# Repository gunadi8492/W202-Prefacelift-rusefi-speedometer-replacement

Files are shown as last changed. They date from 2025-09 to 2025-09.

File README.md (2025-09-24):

# Mercedes-Benz W202 Speedometer Replacement (rusEFI)

This project is a custom **speedometer replacement** for a **1994 Mercedes-Benz W202 C180 (pre-facelift)** running on a **rusEFI open-source standalone ECU**.  

⚠️ **Disclaimer:**  
This is an **open-source project** provided *as-is*, without any warranty or support.  
It is intended strictly for **educational and hobbyist purposes only**.  

---

## 📖 Background

This project builds upon the excellent work by [Pazi88](https://github.com/pazi88/E12_CAN_gauges), originally designed for a BMW E12 speedometer.  

Test implementation has been successfully tested with **rusEFI Dash CANBUS** with a BMW E46 CAN Dash setting, supporting:  
- **RPM**  
- **VSS (Vehicle Speed Sensor)**  
- **CLT (Coolant Temperature)**  

---

## 📟 Hardware Integration

For this adaptation, additional components were introduced:  
- **Nextion Enhanced 3.5” display**  
- **STM32F103C8T6 “Blue Pill” MCU**  

These allow enhanced visualization of live ECU data.  

The **schematic and hardware design** were adapted specifically to meet the requirements of this W202 project.  

---

## 💻 Firmware Status

- Development for the **STM32F103C8T6** firmware is still in progress.  
- For working code examples and inspiration, refer to Pazi’s original repository.  

---

## ⚠️ Important Notice

- ✅ **Responsibility**: You are solely responsible for checking and complying with all **local laws and regulations** before using this project.  
- ✅ **Road Use**: Compliance with vehicle safety and legal standards for public road use is mandatory.  
- ✅ **Liability**: No liability is accepted for misuse, damages, or legal issues resulting from use of this project.  
- 🚫 **Commercial Use**: Strictly prohibited.  
- 📌 **Recommendation**: Ensure you fully understand the project before attempting implementation.  

---

## 📜 License

This project is open-source, non-commercial, and intended for **educational/hobbyist purposes only**.  
Please respect the open-source spirit of this project — it is not to be used for making money

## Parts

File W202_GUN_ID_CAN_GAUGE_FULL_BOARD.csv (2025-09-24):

Reference | Value | Footprint | Datasheet | Qty | DNP | Exclude from BOM | Exclude from Board
ABS1,ALTR1,BRAKE1,BULB_FAIL1,CEL1,CLT_LV1,CLUSTER_LIGHT_1,CLUSTER_LIGHT_2,CLUSTER_LIGHT_3,CLUSTER_LIGHT_4,HI-BEAM1,LEFT_SIGNAL1,OIL_PRESS1,PAD_WEAR1,RIGHT_SIGNAL1,SAFETY_BELT1,SRS1,TLSC_LOCK1,WIPER_LV1 | LED | LED_SMD:LED_Everlight-SMD3528_3.5x2.8mm_67-21ST | ~ | 19
ACTIVE1 | Buzzer | Buzzer_Beeper:Buzzer_TDK_PS1240P02BT_D12.2mm_H6.5mm | ~ | 1
BT1 | CR1220-2 | footprints:HARWIN_S8411-45R | ~ | 1
C1,C4,C5,C8,C9,C10,C11,C12,C13,C15,C16,C18,C19,C20,C22,C23,C24,C25,C26,C27,C28,C32,C34,C36,C37,C38 | 100nF | Capacitor_SMD:C_0805_2012Metric | ~ | 26
C2,C7,C39,C40,Cdec3 | 10uF | Capacitor_SMD:C_0805_2012Metric | ~ | 5
C6,C21,C29 | 47uF | Capacitor_Tantalum_SMD:CP_EIA-3528-21_Kemet-B_HandSolder | ~ | 3
C14,C17,C31 | 10nF | Capacitor_SMD:C_0805_2012Metric | ~ | 3
C30 | 100uF | Capacitor_SMD:C_0805_2012Metric | ~ | 1
C33,Csmooth2 | 4.7uF | Capacitor_SMD:C_0805_2012Metric | ~ | 2
C35 | 10uF | Capacitor_Tantalum_SMD:CP_EIA-3216-18_Kemet-A_HandSolder | ~ | 1
Cdec4,Cfilter1 | 0.1uF | Capacitor_SMD:C_0805_2012Metric | ~ | 2
CLT1,RPM1,VSS1 | SM | footprints:X27-168__V2 | http://www.infineon.com/dgdl/Application-Note-TLE8110EE_driving_UniPolarStepperMotor_V1.1.pdf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 | 3
D1,D5 | BZT52C5V6 | Diode_SMD:D_SOD-123 | ~ | 2
D2,D3 | BAT54C | Package_TO_SOT_SMD:SOT-23 | http://www.diodes.com/_files/datasheets/ds11005.pdf | 2
D4,D6 | D_Zener | Diode_SMD:D_MiniMELF | ~ | 2
D21,D_ALTR1 | 1N4007 | Diode_SMD:D_SMA_Handsoldering | ~ | 2
D22 | B160-13-F | Diode_SMD:D_SMA_Handsoldering | ~ | 1
D23,D24,D25,D26,D27,D28,D29,D30,D31,D32,D33,D34 | 1N4148 | Diode_SMD:D_SOD-123 | ~ | 12
D36,D38,D40 | SMAJ18A | Diode_SMD:D_SMA | ~ | 3
D37 | B160-13-F | Diode_SMD:D_SMA | ~ | 1
DF13,DF14,DF15,DF16,DF17,DF18,DF19,DF20,DF21,DF22,DF23,DF24 | LED | LED_SMD:LED_0805_2012Metric | ~ | 12
F1 | Fuse | Fuse:Fuse_0805_2012Metric | ~ | 1
J1 | Conn_02x15_Top_Bottom | Connector_IDC:IDC-Header_2x15_P2.54mm_Vertical | ~ | 1
J2,J12 | RPM | Connector_PinHeader_2.54mm:PinHeader_1x04_P2.54mm_Vertical | ~ | 2
J3,J13 | VSS | Connector_PinHeader_2.54mm:PinHeader_1x04_P2.54mm_Vertical | ~ | 2
J4,J14 | CLT | Connector_PinHeader_2.54mm:PinHeader_1x04_P2.54mm_Vertical | ~ | 2
J5,J15 | FUEL | Connector_PinHeader_2.54mm:PinHeader_1x04_P2.54mm_Vertical | ~ | 2
J7 | DISPLAY 1 | Connector_PinHeader_2.54mm:PinHeader_1x07_P2.54mm_Vertical | ~ | 1
J8 | DISPLAY 2 | Connector_PinHeader_2.54mm:PinHeader_1x07_P2.54mm_Vertical | ~ | 1
JN1 | NEXTION | Connector_PinHeader_2.54mm:PinHeader_1x04_P2.54mm_Vertical | ~ | 1
J_LED1,J_ULN1 | Conn_01x12 | Connector_PinHeader_2.00mm:PinHeader_1x12_P2.00mm_Horizontal | ~ | 2
L1 | 15uH | Inductor_SMD:L_Vishay_IFSC-1515AH_4x4x1.8mm | ~ | 1
Q1 | AO3401 | Package_TO_SOT_SMD:SOT-23 | https://ngspice.sourceforge.io/docs/ngspice-html-manual/manual.xhtml#cha_MOSFETs | 1
Q2,Q3,Q4 | AO3400 | Package_TO_SOT_SMD:SOT-23 | https://ngspice.sourceforge.io/docs/ngspice-html-manual/manual.xhtml#cha_MOSFETs | 3
R1,R7,R8,R14,RR6,RR7,R_CL9 | 1K | Resistor_SMD:R_0805_2012Metric | ~ | 7
R2,R4,R9,R10,R11,R12,R13,R_CL8,R_CL10,R_CL13,R_CL15,R_CL17,R_WL1,R_WL9,R_WL11,R_WL13 | 10K | Resistor_SMD:R_0805_2012Metric | ~ | 16
R3,R6,R18 | 4.7K | Resistor_SMD:R_0805_2012Metric | ~ | 3
R5 | 120 | Resistor_SMD:R_0805_2012Metric | ~ | 1
R15 | 100 | Resistor_SMD:R_2512_6332Metric | ~ | 1
R16,R_BUZZER1,R_CL18,R_CL19,R_WL2 | 100K | Resistor_SMD:R_0805_2012Metric | ~ | 5
RF13,RF14,RF15,RF16,RF17,RF18,RF19,RF20,RF21,RF22,RF23,RF24 | 330 | Resistor_SMD:R_0603_1608Metric | ~ | 12
RV1 | 14D220K | Varistor:RV_Disc_D12mm_W4.2mm_P7.5mm | ~ | 1
R_ABS1,R_ALT1,R_BELT1,R_BRAKE1,R_BULB1,R_CEL1,R_CLT1,R_HI_B1,R_OP1,R_PAD1,R_TLSC1,R_WPR1 | 470 | Resistor_SMD:R_0805_2012Metric | ~ | 12
R_ALTR_3W_WIREWOUND1 | 100 | Fuse:Fuse_Littelfuse-NANO2-462 | ~ | 1
R_ALT_J1,R_ALT_J2 | 0 | Resistor_SMD:R_0805_2012Metric | ~ | 2
R_BUZZ1,R_GATE1,R_WL6 | 100 | Resistor_SMD:R_0805_2012Metric | ~ | 3
R_CL1 | 1.2 | Resistor_SMD:R_2512_6332Metric | ~ | 1
R_CL4,R_CL5,R_CL6,R_CL7 | 10 | Resistor_SMD:R_0805_2012Metric | ~ | 4
R_CL11 | 22K | Resistor_SMD:R_0805_2012Metric | ~ | 1
R_CL12 | 11K | Resistor_SMD:R_0805_2012Metric | ~ | 1
R_CL14 | 150K | Resistor_SMD:R_0805_2012Metric | ~ | 1
R_CL16,R_WL12 | 47K | Resistor_SMD:R_0805_2012Metric | ~ | 2
R_LEFT1,R_RIGHT1,R_SRS1 | 1K | Resistor_SMD:R_1206_3216Metric | ~ | 3
R_SER2 | 10 | Resistor_SMD:R_2512_6332Metric | ~ | 1
R_TRIM2 | 100 | Potentiometer_SMD:Potentiometer_Bourns_3314J_Vertical | ~ | 1
R_WL10 | 22k | Resistor_SMD:R_0805_2012Metric | ~ | 1
SW1,SW2,SW3 | SW_Push | Button_Switch_THT:SW_PUSH_6mm | ~ | 3
U1 | LM393 | footprints:SO08 | http://www.ti.com/lit/ds/symlink/lm393.pdf | 1
U2,U10,U16 | LM7805_TO220 | Package_TO_SOT_THT:TO-220-3_Vertical | https://www.onsemi.cn/PowerSolutions/document/MC7800-D.PDF | 3
U3,U11 | STM32F103C8T6 | ZC323000:MODULE_ZC323000 |  | 2
U4 | W25Q16JVSS | Package_SO:SOIC-8_5.3x5.3mm_P1.27mm | https://www.winbond.com/hq/support/documentation/levelOne.jsp?__locale=en&DocNo=DA00-W25Q16JV.1 | 1
U5,U12 | MCP2551-I-SN | Package_SO:SOIC-8_3.9x4.9mm_P1.27mm | http://ww1.microchip.com/downloads/en/devicedoc/21667d.pdf | 2
U6 | MIC29151-5.0WU-TR | TO-263-5_MCH | MIC29151-5.0WU-TR | 1
U7 | VN5R003H-E | HPAK_R003H-E_STM | https://www.st.com/resource/en/datasheet/vn5r003h-e.pdf | 1
U8,U13 | AMS1117-3.3 | Package_TO_SOT_SMD:SOT-223-3_TabPin2 | http://www.advanced-monolithic.com/pdf/ds1117.pdf | 2
U9 | AX1201728SG | Package_SO:SOIC-28W_7.5x17.9mm_P1.27mm | https://store.comet.bg/en/Catalogue/Product/5150499/ | 1
U14 | AL8860WT | Package_TO_SOT_SMD:TSOT-23-5 | https://www.diodes.com/assets/Datasheets/AL8860.pdf | 1
U15,U20 | ULN2803A | Package_SO:SOIC-20W_7.5x12.8mm_P1.27mm | http://www.ti.com/lit/ds/symlink/uln2803a.pdf | 2
U17 | 74HC14D | footprints:SOIC127P600X175-14N |  | 1
U18 | 74HC4066D_653 | footprints:SOIC127P600X175-14N |  | 1
U19 | CD4017BM96 | footprints:SOIC127P600X175-16N |  | 1
ULN1 | ULN2003A | Package_SO:SOIC-16_3.9x9.9mm_P1.27mm | http://www.ti.com/lit/ds/symlink/uln2003a.pdf | 1

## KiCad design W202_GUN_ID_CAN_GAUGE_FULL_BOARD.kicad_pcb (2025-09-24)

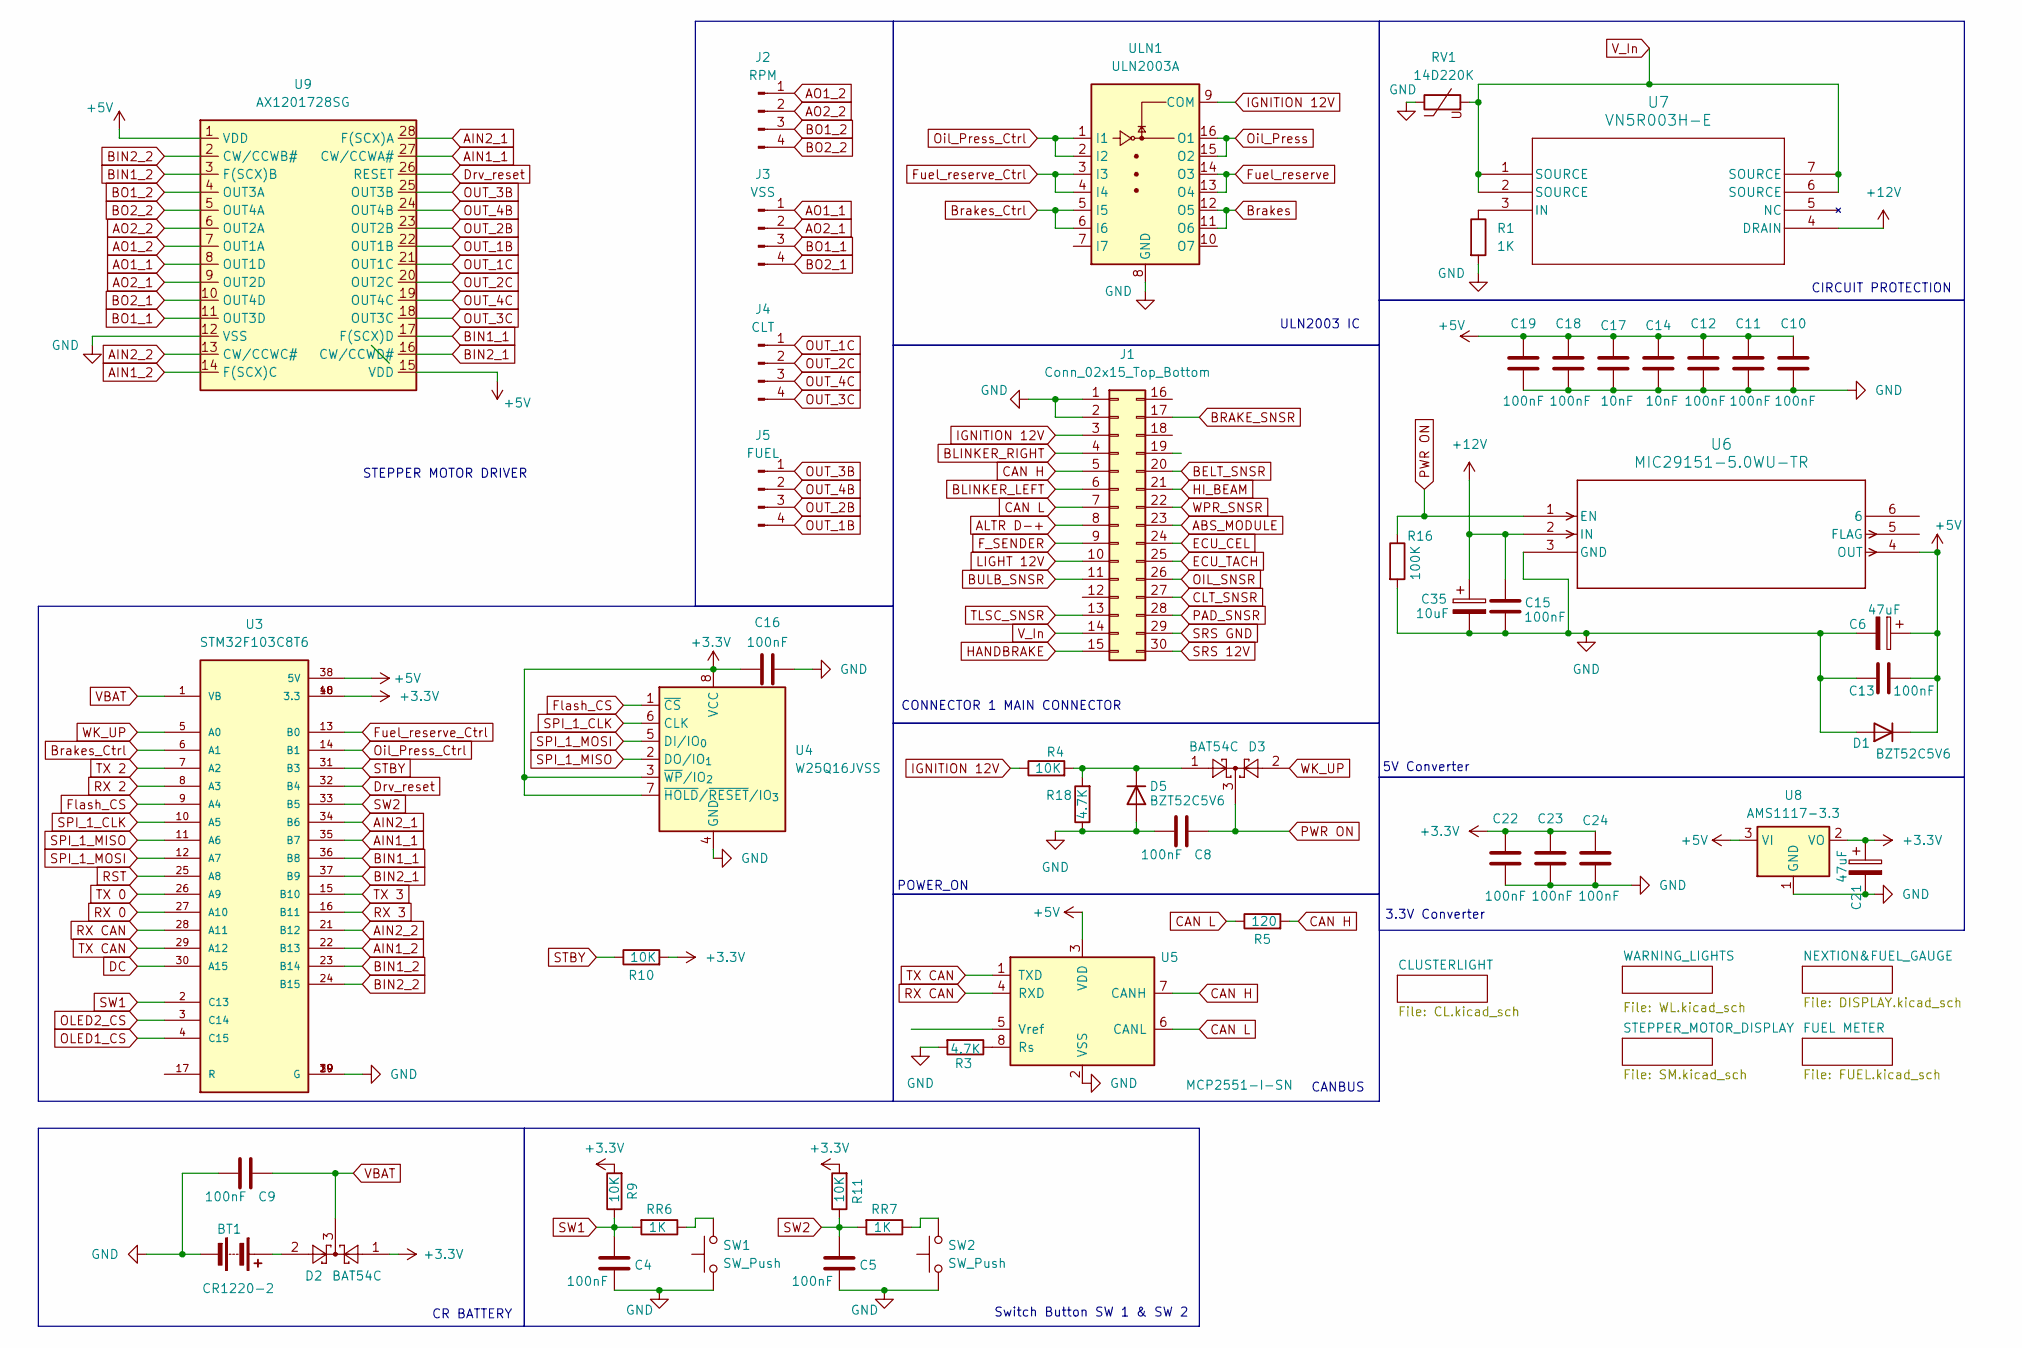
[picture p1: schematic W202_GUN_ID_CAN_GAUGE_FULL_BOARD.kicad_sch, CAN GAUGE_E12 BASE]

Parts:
BT1: CR1220-2; HARWIN_S8411-45R
C4, C5, C8, C9, C10, C11, C12, C13, C15, C16, C18, C19, C22, C23, C24: 100nF; C_0805_2012Metric
C6, C21: 47uF; CP_EIA-3528-21_Kemet-B_HandSolder
C14, C17: 10nF; C_0805_2012Metric
C35: 10uF; CP_EIA-3216-18_Kemet-A_HandSolder
D1, D5: BZT52C5V6; D_SOD-123
D2, D3: BAT54C; SOT-23
J1: Conn_02x15_Top_Bottom; IDC-Header_2x15_P2.54mm_Vertical
J2: RPM; PinHeader_1x04_P2.54mm_Vertical
J3: VSS; PinHeader_1x04_P2.54mm_Vertical
J4: CLT; PinHeader_1x04_P2.54mm_Vertical
J5: FUEL; PinHeader_1x04_P2.54mm_Vertical
R1: 1K; R_0805_2012Metric
R3, R18: 4.7K; R_0805_2012Metric
R4, R9, R10, R11: 10K; R_0805_2012Metric
R5: 120; R_0805_2012Metric
R16: 100K; R_0805_2012Metric
RR6, RR7: 1K; R_0805_2012Metric
RV1: 14D220K; RV_Disc_D12mm_W4.2mm_P7.5mm
SW1, SW2: SW_Push; SW_PUSH_6mm
U3: STM32F103C8T6; MODULE_ZC323000; PARTREV N/A
U4: W25Q16JVSS; SOIC-8_5.3x5.3mm_P1.27mm
U5: MCP2551-I-SN; SOIC-8_3.9x4.9mm_P1.27mm
U6: MIC29151-5.0WU-TR; TO-263-5_MCH
U7: VN5R003H-E; HPAK_R003H-E_STM
U8: AMS1117-3.3; SOT-223-3_TabPin2
U9: AX1201728SG; SOIC-28W_7.5x17.9mm_P1.27mm
ULN1: ULN2003A; SOIC-16_3.9x9.9mm_P1.27mm

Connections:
+3.3V: C16.2, C21.1, C22.1, C23.1, C24.1, D2.1, R9.2, R10.2, R11.2, U3.18 (3.3), U3.40 (3.3), U4.3 (~WP/IO_{2}), U4.7 (~HOLD/~RESET/IO_{3}), U4.8 (VCC), U8.2 (VO); also elsewhere on the board
+5V: C6.1, C10.1, C11.1, C12.1, C13.1, C14.1, C17.1, C18.1, C19.1, D1.1 (K), U3.38 (5V), U5.3 (VDD), U6.4 (OUT), U8.3 (VI), U9.1 (VDD), U9.15 (VDD); also elsewhere on the board
+12V: C15.1, C35.1, U6.2 (IN), U7.4 (DRAIN)
ABS_MODULE: J1.23; also elsewhere on the board
AIN1_1: U3.35 (B7), U9.27 (CW/CCWA#)
AIN1_2: U3.22 (B13), U9.14 (F(SCX)C)
AIN2_1: U3.34 (B6), U9.28 (F(SCX)A)
AIN2_2: U3.21 (B12), U9.13 (CW/CCWC#)
ALTR D-+: J1.8; also elsewhere on the board
AO1_1: J3.1, U9.8 (OUT1D); also elsewhere on the board
AO1_2: J2.1, U9.7 (OUT1A); also elsewhere on the board
AO2_1: J3.2, U9.9 (OUT2D); also elsewhere on the board
AO2_2: J2.2, U9.6 (OUT2A); also elsewhere on the board
BELT_SNSR: J1.20; also elsewhere on the board
BIN1_1: U3.36 (B8), U9.17 (F(SCX)D)
BIN1_2: U3.23 (B14), U9.3 (F(SCX)B)
BIN2_1: U3.37 (B9), U9.16 (CW/CCWD#)
BIN2_2: U3.24 (B15), U9.2 (CW/CCWB#)
BLINKER_LEFT: J1.6; also elsewhere on the board
BLINKER_RIGHT: J1.4; also elsewhere on the board
BO1_1: J3.3, U9.11 (OUT3D); also elsewhere on the board
BO1_2: J2.3, U9.4 (OUT3A); also elsewhere on the board
BO2_1: J3.4, U9.10 (OUT4D); also elsewhere on the board
BO2_2: J2.4, U9.5 (OUT4A); also elsewhere on the board
BRAKE_SNSR: J1.15, J1.17; also elsewhere on the board
BULB_SNSR: J1.11; also elsewhere on the board
Brakes_Ctrl: U3.6 (A1), ULN1.5 (I5), ULN1.6 (I6)
CAN H: J1.5, R5.2, U5.7 (CANH); also elsewhere on the board
CAN L: J1.7, R5.1, U5.6 (CANL); also elsewhere on the board
CLT_SNSR: J1.27; also elsewhere on the board
DC: U3.30 (A15); also elsewhere on the board
Drv_reset: U3.32 (B4), U9.26 (RESET)
ECU_CEL: J1.24; also elsewhere on the board
ECU_TACH: J1.25; also elsewhere on the board
F_SENDER: J1.9; also elsewhere on the board
Flash_CS: U3.9 (A4), U4.1 (~CS)
Fuel_reserve_Ctrl: U3.13 (B0), ULN1.3 (I3), ULN1.4 (I4)
GND: BT1.2 (-), C4.2, C5.2, C6.2, C8.2, C9.2, C10.2, C11.2, C12.2, C13.2, C14.2, C15.2, C16.1, C17.2, C18.2, C19.2, C21.2, C22.2, C23.2, C24.2, C35.2, D1.2 (A), D5.2 (A), J1.1, J1.2, R1.2, R3.2, R16.2, R18.1, RV1.1, SW1.1, SW2.1, U3.19 (G), U3.20 (G), U3.39 (G), U4.4 (GND), U5.2 (VSS), U6.3 (GND), U8.1 (GND), U9.12 (VSS), ULN1.8 (GND); also elsewhere on the board
HI_BEAM: J1.21; also elsewhere on the board
LIGHT 12V: J1.10; also elsewhere on the board
unnamed: BT1.1 (+), D2.2
unnamed: D3.1, D5.1 (K), R4.2, R18.2
unnamed: RR6.1, SW1.2
unnamed: RR7.1, SW2.2
unnamed: R3.1, U5.8 (Rs)
unnamed: R1.1, U7.3 (IN)
unnamed: ULN1.11 (O6), ULN1.12 (O5)
unnamed: ULN1.13 (O4), ULN1.14 (O3)
unnamed: ULN1.15 (O2), ULN1.16 (O1)
OIL_SNSR: J1.26; also elsewhere on the board
OLED1_CS: U3.4 (C15); also elsewhere on the board
OLED2_CS: U3.3 (C14); also elsewhere on the board
OUT_1B: J5.4, U9.22 (OUT1B)
OUT_1C: J4.1, U9.21 (OUT1C); also elsewhere on the board
OUT_2B: J5.3, U9.23 (OUT2B)
OUT_2C: J4.2, U9.20 (OUT2C); also elsewhere on the board
OUT_3B: J5.1, U9.25 (OUT3B)
OUT_3C: J4.4, U9.18 (OUT3C); also elsewhere on the board
OUT_4B: J5.2, U9.24 (OUT4B)
OUT_4C: J4.3, U9.19 (OUT4C); also elsewhere on the board
Oil_Press_Ctrl: U3.14 (B1), ULN1.1 (I1), ULN1.2 (I2)
PAD_SNSR: J1.28; also elsewhere on the board
PWR ON: C8.1, D3.3, R16.1, U6.1 (EN)
RST: U3.25 (A8); also elsewhere on the board
RX 0: U3.27 (A10)
RX 2: U3.8 (A3)
RX 3: U3.16 (B11)
RX CAN: U3.28 (A11), U5.4 (RXD); also elsewhere on the board
SPI_1_CLK: U3.10 (A5), U4.6 (CLK); also elsewhere on the board
SPI_1_MISO: U3.11 (A6), U4.2 (DO/IO_{1})
SPI_1_MOSI: U3.12 (A7), U4.5 (DI/IO_{0}); also elsewhere on the board
SRS 12V: J1.30; also elsewhere on the board
SRS GND: J1.29; also elsewhere on the board
STBY: R10.1, U3.31 (B3)
SW1: C4.1, R9.1, RR6.2, U3.2 (C13)
SW2: C5.1, R11.1, RR7.2, U3.33 (B5)
TLSC_SNSR: J1.13; also elsewhere on the board
TX 0: U3.26 (A9)
TX 2: U3.7 (A2)
TX 3: U3.15 (B10)
TX CAN: U3.29 (A12), U5.1 (TXD); also elsewhere on the board
VBAT: C9.1, D2.3, U3.1 (VB)
V_In: J1.14, RV1.2, U7.1 (SOURCE), U7.2 (SOURCE), U7.6 (SOURCE), U7.7 (SOURCE)
WK_UP: D3.2, U3.5 (A0)
WPR_SNSR: J1.22; also elsewhere on the board

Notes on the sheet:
ULN2003 IC
CONNECTOR 1 MAIN CONNECTOR
POWER_ON
CR BATTERY
3.3V Converter
CANBUS
CIRCUIT PROTECTION
Switch Button SW 1 & SW 2
STEPPER MOTOR DRIVER
5V Converter

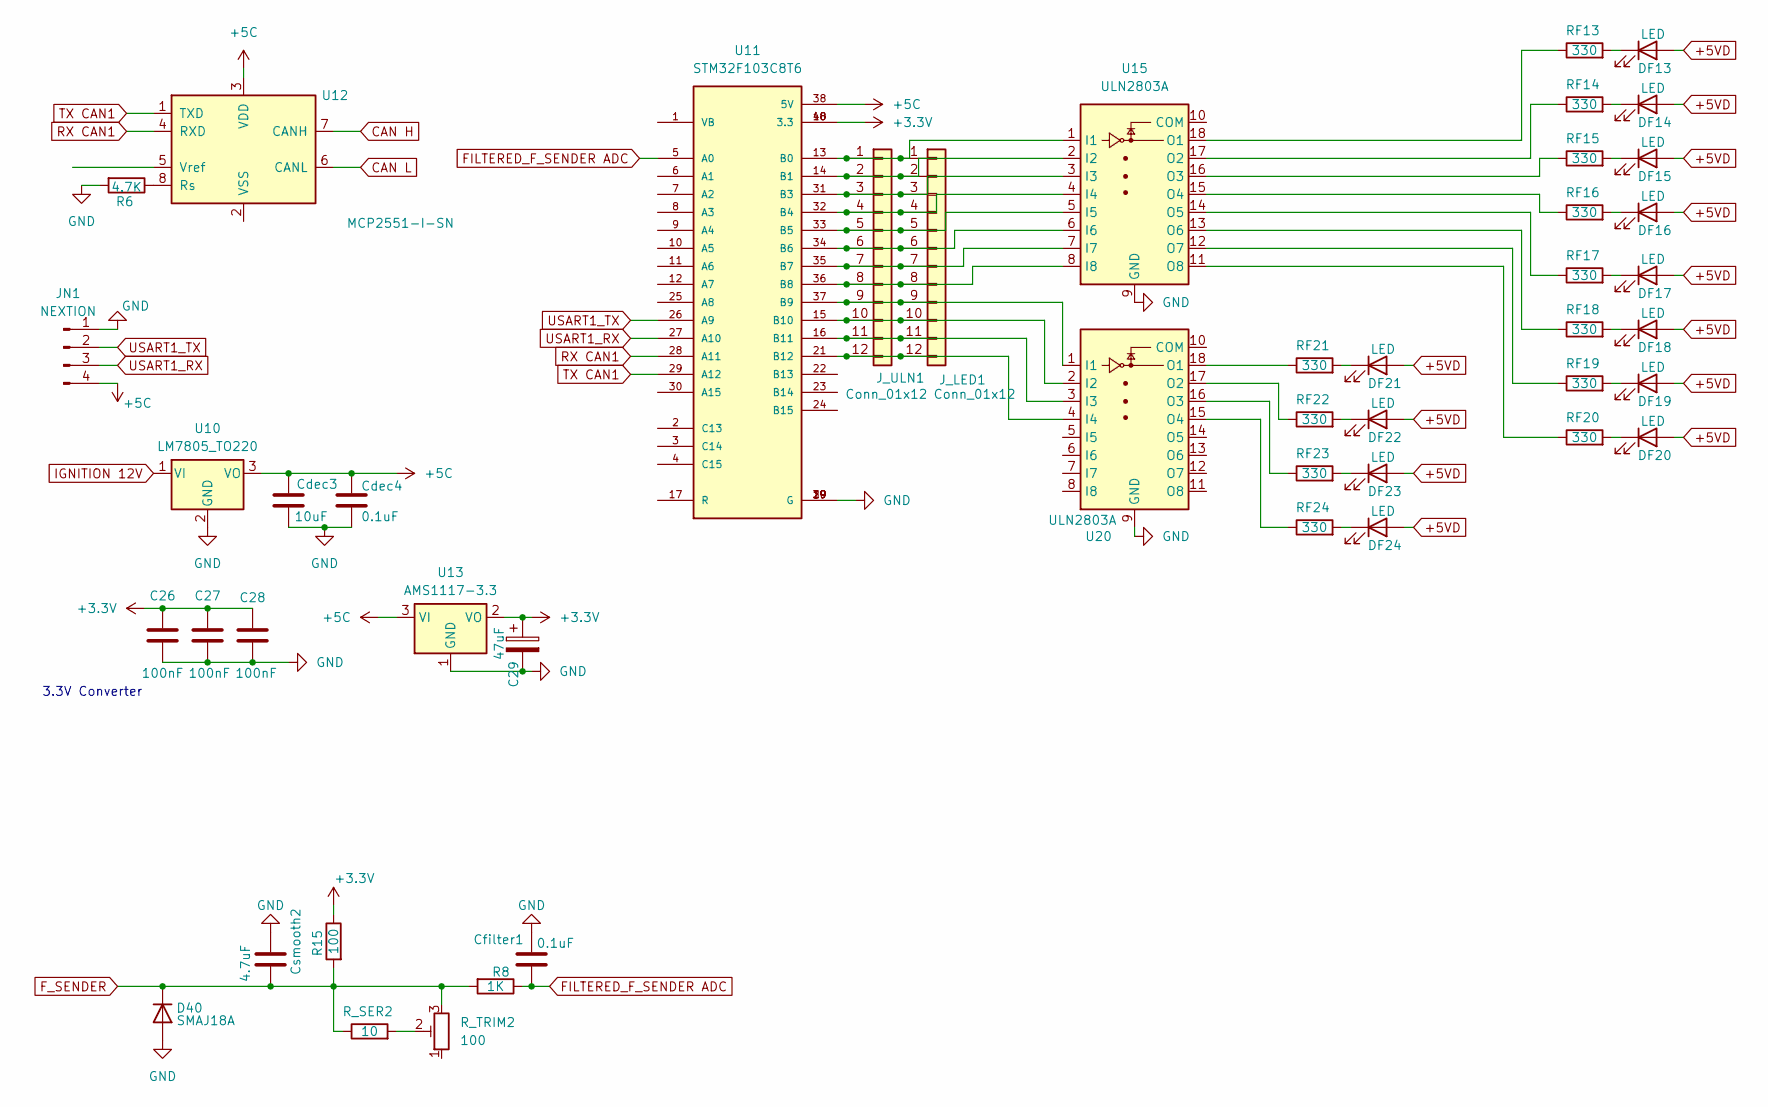
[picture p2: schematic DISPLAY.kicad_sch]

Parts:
C26, C27, C28: 100nF; C_0805_2012Metric
C29: 47uF; CP_EIA-3528-21_Kemet-B_HandSolder
Cdec3: 10uF; C_0805_2012Metric
Cdec4: 0.1uF; C_0805_2012Metric
Cfilter1: 0.1uF; C_0805_2012Metric
Csmooth2: 4.7uF; C_0805_2012Metric
D40: SMAJ18A; D_SMA
DF13, DF14, DF15, DF16, DF17, DF18, DF19, DF20, DF21, DF22, DF23, DF24: LED; LED_0805_2012Metric
JN1: NEXTION; PinHeader_1x04_P2.54mm_Vertical
J_LED1: Conn_01x12; PinHeader_1x12_P2.00mm_Horizontal
J_ULN1: Conn_01x12; PinHeader_1x12_P2.00mm_Horizontal
R6: 4.7K; R_0805_2012Metric
R8: 1K; R_0805_2012Metric
R15: 100; R_2512_6332Metric
RF13, RF14, RF15, RF16, RF17, RF18, RF19, RF20, RF21, RF22, RF23, RF24: 330; R_0603_1608Metric
R_SER2: 10; R_2512_6332Metric
R_TRIM2: 100; Potentiometer_Bourns_3314J_Vertical
U10: LM7805_TO220; TO-220-3_Vertical
U11: STM32F103C8T6; MODULE_ZC323000; PARTREV N/A
U12: MCP2551-I-SN; SOIC-8_3.9x4.9mm_P1.27mm
U13: AMS1117-3.3; SOT-223-3_TabPin2
U15, U20: ULN2803A; SOIC-20W_7.5x12.8mm_P1.27mm

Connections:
+3.3V: C26.1, C27.1, C28.1, C29.1, R15.1, U11.18 (3.3), U11.40 (3.3), U13.2 (VO); also elsewhere on the board
+5C: Cdec3.1, Cdec4.1, JN1.4, U10.3 (VO), U11.38 (5V), U12.3 (VDD), U13.3 (VI); also elsewhere on the board
+5VD: DF13.2 (A), DF14.2 (A), DF15.2 (A), DF16.2 (A), DF17.2 (A), DF18.2 (A), DF19.2 (A), DF20.2 (A), DF21.2 (A), DF22.2 (A), DF23.2 (A), DF24.2 (A); also elsewhere on the board
CAN H: U12.7 (CANH); also elsewhere on the board
CAN L: U12.6 (CANL); also elsewhere on the board
FILTERED_F_SENDER ADC: Cfilter1.1, R8.1, U11.5 (A0)
F_SENDER: Csmooth2.2, D40.1 (K), R8.2, R15.2, R_SER2.1, R_TRIM2.3; also elsewhere on the board
GND: C26.2, C27.2, C28.2, C29.2, Cdec3.2, Cdec4.2, Cfilter1.2, Csmooth2.1, D40.2 (A), JN1.1, R6.2, U10.2 (GND), U11.19 (G), U11.20 (G), U11.39 (G), U13.1 (GND), U15.9 (GND), U20.9 (GND); also elsewhere on the board
unnamed: DF13.1 (K), RF13.2
unnamed: DF14.1 (K), RF14.2
unnamed: DF15.1 (K), RF15.2
unnamed: DF16.1 (K), RF16.2
unnamed: DF17.1 (K), RF17.2
unnamed: DF18.1 (K), RF18.2
unnamed: DF19.1 (K), RF19.2
unnamed: DF20.1 (K), RF20.2
unnamed: DF21.1 (K), RF21.2
unnamed: DF22.1 (K), RF22.2
unnamed: DF23.1 (K), RF23.2
unnamed: DF24.1 (K), RF24.2
unnamed: J_LED1.1, J_ULN1.1, U11.13 (B0), U15.1 (I1)
unnamed: J_LED1.2, J_ULN1.2, U11.14 (B1), U15.2 (I2)
unnamed: J_LED1.3, J_ULN1.3, U11.31 (B3), U15.3 (I3)
unnamed: J_LED1.4, J_ULN1.4, U11.32 (B4), U15.4 (I4)
unnamed: J_LED1.5, J_ULN1.5, U11.33 (B5), U15.5 (I5)
unnamed: J_LED1.6, J_ULN1.6, U11.34 (B6), U15.6 (I6)
unnamed: J_LED1.7, J_ULN1.7, U11.35 (B7), U15.7 (I7)
unnamed: J_LED1.8, J_ULN1.8, U11.36 (B8), U15.8 (I8)
unnamed: J_LED1.9, J_ULN1.9, U11.37 (B9), U20.1 (I1)
unnamed: J_LED1.10, J_ULN1.10, U11.15 (B10), U20.2 (I2)
unnamed: J_LED1.11, J_ULN1.11, U11.16 (B11), U20.3 (I3)
unnamed: J_LED1.12, J_ULN1.12, U11.21 (B12), U20.4 (I4)
unnamed: R_SER2.2, R_TRIM2.2
unnamed: R6.1, U12.8 (Rs)
unnamed: RF13.1, U15.18 (O1)
unnamed: RF14.1, U15.17 (O2)
unnamed: RF15.1, U15.16 (O3)
unnamed: RF16.1, U15.15 (O4)
unnamed: RF17.1, U15.14 (O5)
unnamed: RF18.1, U15.13 (O6)
unnamed: RF19.1, U15.12 (O7)
unnamed: RF20.1, U15.11 (O8)
unnamed: RF21.1, U20.18 (O1)
unnamed: RF22.1, U20.17 (O2)
unnamed: RF23.1, U20.16 (O3)
unnamed: RF24.1, U20.15 (O4)
RX CAN1: U11.28 (A11), U12.4 (RXD)
TX CAN1: U11.29 (A12), U12.1 (TXD)
USART1_RX: JN1.3, U11.27 (A10)
USART1_TX: JN1.2, U11.26 (A9)

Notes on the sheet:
3.3V Converter

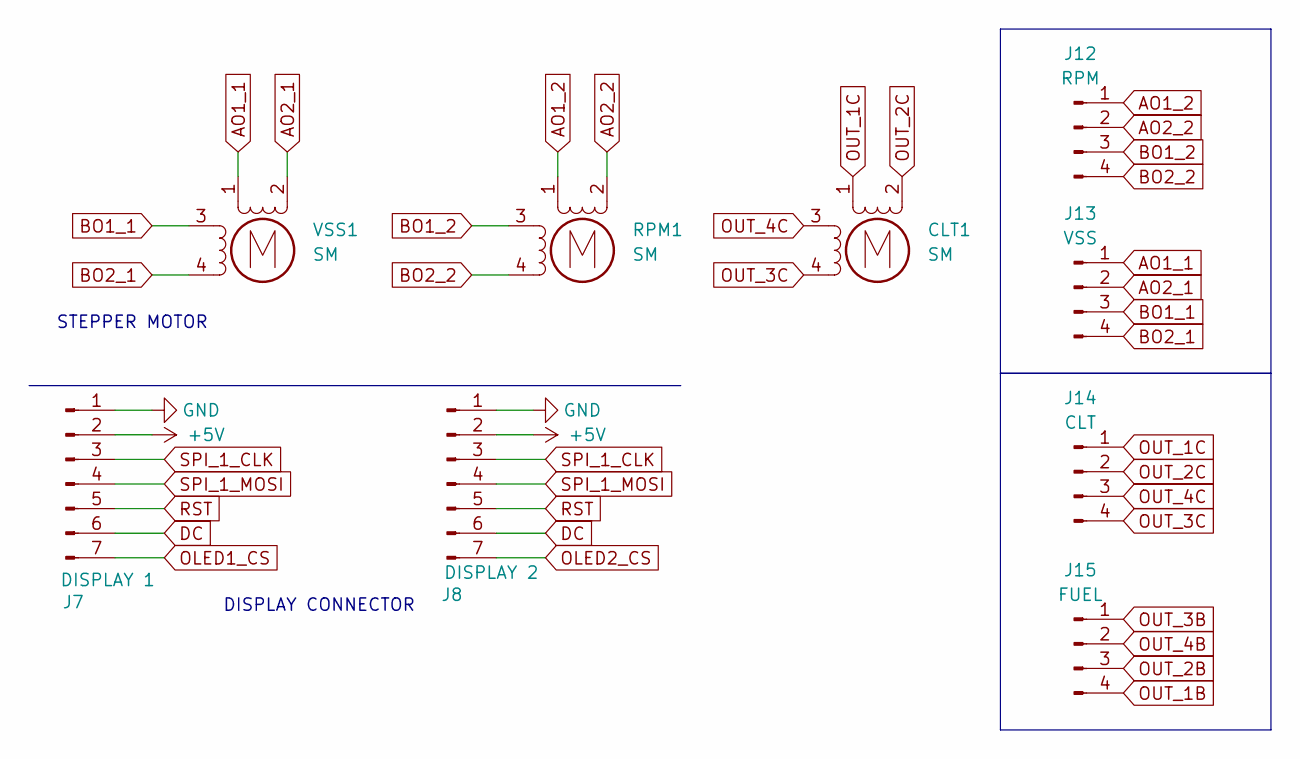
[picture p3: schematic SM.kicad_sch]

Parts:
CLT1: SM; X27-168__V2
J7: DISPLAY 1; PinHeader_1x07_P2.54mm_Vertical
J8: DISPLAY 2; PinHeader_1x07_P2.54mm_Vertical
J12: RPM; PinHeader_1x04_P2.54mm_Vertical
J13: VSS; PinHeader_1x04_P2.54mm_Vertical
J14: CLT; PinHeader_1x04_P2.54mm_Vertical
J15: FUEL; PinHeader_1x04_P2.54mm_Vertical
RPM1: SM; X27-168__V2
VSS1: SM; X27-168__V2

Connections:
+5V: J7.2, J8.2; also elsewhere on the board
AO1_1: J13.1, VSS1.1; also elsewhere on the board
AO1_2: J12.1, RPM1.1; also elsewhere on the board
AO2_1: J13.2, VSS1.2 (-); also elsewhere on the board
AO2_2: J12.2, RPM1.2 (-); also elsewhere on the board
BO1_1: J13.3, VSS1.3; also elsewhere on the board
BO1_2: J12.3, RPM1.3; also elsewhere on the board
BO2_1: J13.4, VSS1.4; also elsewhere on the board
BO2_2: J12.4, RPM1.4; also elsewhere on the board
DC: J7.6, J8.6; also elsewhere on the board
GND: J7.1, J8.1; also elsewhere on the board
OLED1_CS: J7.7; also elsewhere on the board
OLED2_CS: J8.7; also elsewhere on the board
OUT_1C: CLT1.1, J14.1; also elsewhere on the board
OUT_2C: CLT1.2 (-), J14.2; also elsewhere on the board
OUT_3C: CLT1.4, J14.4; also elsewhere on the board
OUT_4C: CLT1.3, J14.3; also elsewhere on the board
RST: J7.5, J8.5; also elsewhere on the board
SPI_1_CLK: J7.3, J8.3; also elsewhere on the board
SPI_1_MOSI: J7.4, J8.4; also elsewhere on the board

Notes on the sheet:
DISPLAY CONNECTOR
STEPPER MOTOR

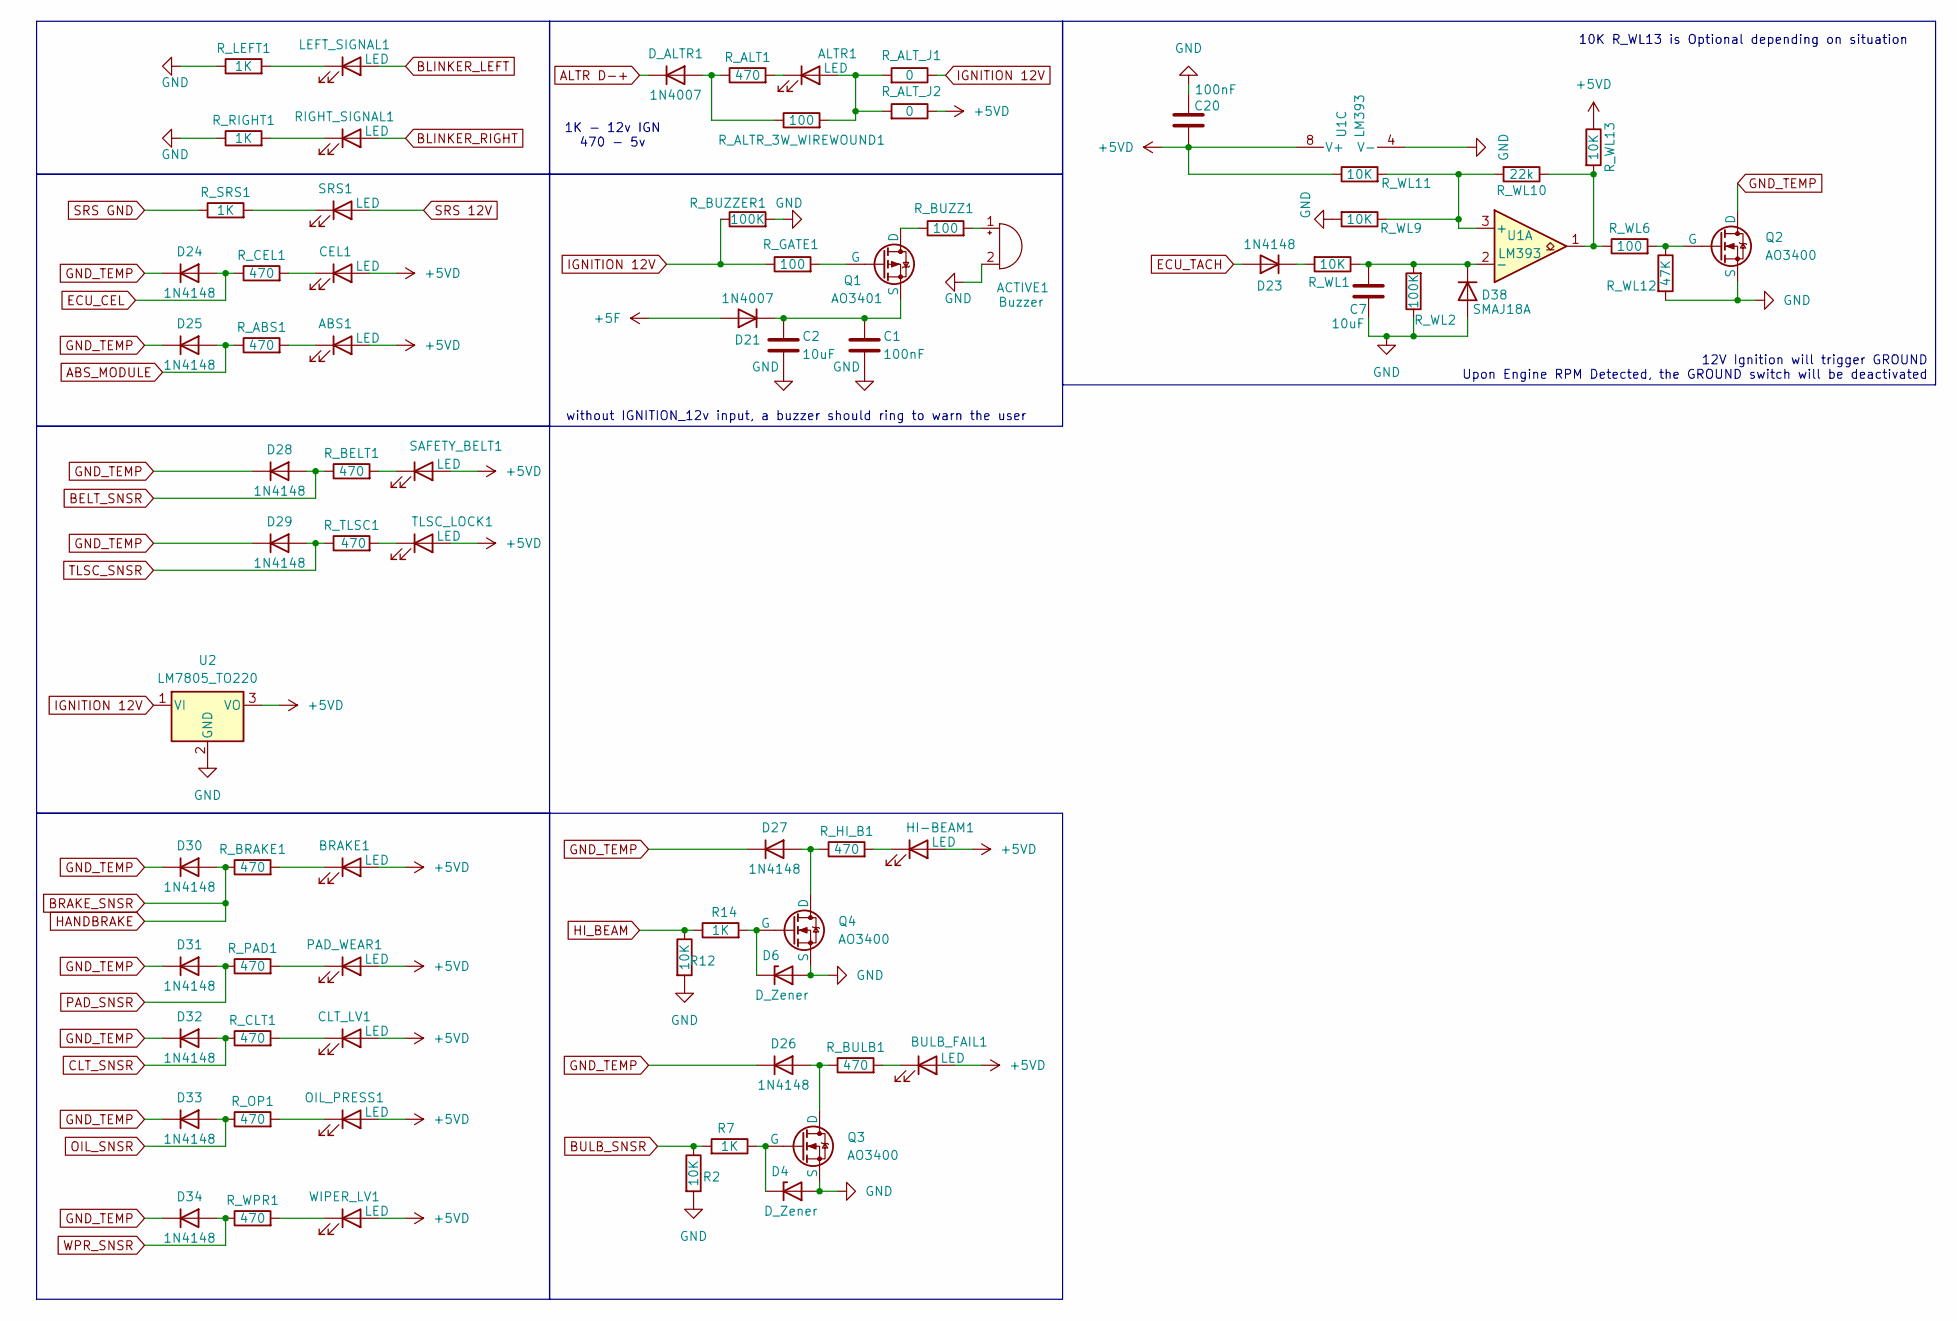
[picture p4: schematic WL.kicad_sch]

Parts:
ABS1: LED; LED_Everlight-SMD3528_3.5x2.8mm_67-21ST
ACTIVE1: Buzzer; Buzzer_TDK_PS1240P02BT_D12.2mm_H6.5mm
ALTR1: LED; LED_Everlight-SMD3528_3.5x2.8mm_67-21ST
BRAKE1: LED; LED_Everlight-SMD3528_3.5x2.8mm_67-21ST
BULB_FAIL1: LED; LED_Everlight-SMD3528_3.5x2.8mm_67-21ST
C1, C20: 100nF; C_0805_2012Metric
C2, C7: 10uF; C_0805_2012Metric
CEL1: LED; LED_Everlight-SMD3528_3.5x2.8mm_67-21ST
CLT_LV1: LED; LED_Everlight-SMD3528_3.5x2.8mm_67-21ST
D4, D6: D_Zener; D_MiniMELF
D21: 1N4007; D_SMA_Handsoldering
D23, D24, D25, D26, D27, D28, D29, D30, D31, D32, D33, D34: 1N4148; D_SOD-123
D38: SMAJ18A; D_SMA
D_ALTR1: 1N4007; D_SMA_Handsoldering
HI-BEAM1: LED; LED_Everlight-SMD3528_3.5x2.8mm_67-21ST
LEFT_SIGNAL1: LED; LED_Everlight-SMD3528_3.5x2.8mm_67-21ST
OIL_PRESS1: LED; LED_Everlight-SMD3528_3.5x2.8mm_67-21ST
PAD_WEAR1: LED; LED_Everlight-SMD3528_3.5x2.8mm_67-21ST
Q1: AO3401; SOT-23
Q2, Q3, Q4: AO3400; SOT-23
R2, R12: 10K; R_0805_2012Metric
R7, R14: 1K; R_0805_2012Metric
RIGHT_SIGNAL1: LED; LED_Everlight-SMD3528_3.5x2.8mm_67-21ST
R_ABS1: 470; R_0805_2012Metric
R_ALT1: 470; R_0805_2012Metric
R_ALTR_3W_WIREWOUND1: 100; Fuse_Littelfuse-NANO2-462
R_ALT_J1, R_ALT_J2: 0; R_0805_2012Metric
R_BELT1: 470; R_0805_2012Metric
R_BRAKE1: 470; R_0805_2012Metric
R_BULB1: 470; R_0805_2012Metric
R_BUZZ1: 100; R_0805_2012Metric
R_BUZZER1: 100K; R_0805_2012Metric
R_CEL1: 470; R_0805_2012Metric
R_CLT1: 470; R_0805_2012Metric
R_GATE1: 100; R_0805_2012Metric
R_HI_B1: 470; R_0805_2012Metric
R_LEFT1: 1K; R_1210_3225Metric_Pad1.30x2.65mm_HandSolder
R_OP1: 470; R_0805_2012Metric
R_PAD1: 470; R_0805_2012Metric
R_RIGHT1: 1K; R_1210_3225Metric_Pad1.30x2.65mm_HandSolder
R_SRS1: 1K; R_1206_3216Metric
R_TLSC1: 470; R_0805_2012Metric
R_WL1, R_WL9, R_WL11, R_WL13: 10K; R_0805_2012Metric
R_WL2: 100K; R_0805_2012Metric
R_WL6: 100; R_0805_2012Metric
R_WL10: 22k; R_0805_2012Metric
R_WL12: 47K; R_0805_2012Metric
R_WPR1: 470; R_0805_2012Metric
SAFETY_BELT1: LED; LED_Everlight-SMD3528_3.5x2.8mm_67-21ST
SRS1: LED; LED_Everlight-SMD3528_3.5x2.8mm_67-21ST
TLSC_LOCK1: LED; LED_Everlight-SMD3528_3.5x2.8mm_67-21ST
U1: LM393; SO08
U2: LM7805_TO220; TO-220-3_Vertical
WIPER_LV1: LED; LED_Everlight-SMD3528_3.5x2.8mm_67-21ST

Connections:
+5F: D21.2 (A); also elsewhere on the board
+5VD: ABS1.2 (A), BRAKE1.2 (A), BULB_FAIL1.2 (A), C20.1, CEL1.2 (A), CLT_LV1.2 (A), HI-BEAM1.2 (A), OIL_PRESS1.2 (A), PAD_WEAR1.2 (A), R_ALT_J2.1, R_WL11.1, R_WL13.1, SAFETY_BELT1.2 (A), TLSC_LOCK1.2 (A), U1.8 (V+), U2.3 (VO), WIPER_LV1.2 (A); also elsewhere on the board
ABS_MODULE: D25.2 (A), R_ABS1.1; also elsewhere on the board
ALTR D-+: D_ALTR1.1 (K); also elsewhere on the board
BELT_SNSR: D28.2 (A), R_BELT1.1; also elsewhere on the board
BLINKER_LEFT: LEFT_SIGNAL1.2 (A); also elsewhere on the board
BLINKER_RIGHT: RIGHT_SIGNAL1.2 (A); also elsewhere on the board
BRAKE_SNSR: D30.2 (A), R_BRAKE1.1; also elsewhere on the board
BULB_SNSR: R2.1, R7.2; also elsewhere on the board
CLT_SNSR: D32.2 (A), R_CLT1.1; also elsewhere on the board
ECU_CEL: D24.2 (A), R_CEL1.1; also elsewhere on the board
ECU_TACH: D23.2 (A); also elsewhere on the board
GND: ACTIVE1.2 (-), C1.2, C2.2, C7.2, C20.2, D4.2 (A), D6.2 (A), D38.2 (A), Q2.3 (S), Q3.3 (S), Q4.3 (S), R2.2, R12.2, R_BUZZER1.2, R_LEFT1.1, R_RIGHT1.1, R_WL2.1, R_WL9.2, R_WL12.2, U1.4 (V-), U2.2 (GND); also elsewhere on the board
GND_TEMP: D24.1 (K), D25.1 (K), D26.1 (K), D27.1 (K), D28.1 (K), D29.1 (K), D30.1 (K), D31.1 (K), D32.1 (K), D33.1 (K), D34.1 (K), Q2.1 (D)
HI_BEAM: R12.1, R14.1; also elsewhere on the board
unnamed: ABS1.1 (K), R_ABS1.2
unnamed: ACTIVE1.1 (+), R_BUZZ1.2
unnamed: ALTR1.2 (A), R_ALTR_3W_WIREWOUND1.2, R_ALT_J1.2, R_ALT_J2.2
unnamed: ALTR1.1 (K), R_ALT1.2
unnamed: BRAKE1.1 (K), R_BRAKE1.2
unnamed: BULB_FAIL1.1 (K), R_BULB1.2
unnamed: CEL1.1 (K), R_CEL1.2
unnamed: CLT_LV1.1 (K), R_CLT1.2
unnamed: D4.1 (K), Q3.2 (G), R7.1
unnamed: D6.1 (K), Q4.2 (G), R14.2
unnamed: C1.1, C2.1, D21.1 (K), Q1.3 (S)
unnamed: D23.1 (K), R_WL1.2
unnamed 69: D26.2 (A), Q3.1 (D), R_BULB1.1; also elsewhere on the board
unnamed 70: D27.2 (A), Q4.1 (D), R_HI_B1.1; also elsewhere on the board
unnamed: C7.1, D38.1 (K), R_WL1.1, R_WL2.2, U1.2 (-)
unnamed: D_ALTR1.2 (A), R_ALT1.1, R_ALTR_3W_WIREWOUND1.1
unnamed: HI-BEAM1.1 (K), R_HI_B1.2
unnamed: LEFT_SIGNAL1.1 (K), R_LEFT1.2
unnamed: OIL_PRESS1.1 (K), R_OP1.2
unnamed: PAD_WEAR1.1 (K), R_PAD1.2
unnamed: Q1.1 (D), R_BUZZ1.1
unnamed: Q1.2 (G), R_GATE1.2
unnamed 104: Q2.2 (G), R_WL6.2, R_WL12.1; also elsewhere on the board
unnamed: RIGHT_SIGNAL1.1 (K), R_RIGHT1.2
unnamed: R_WL6.1, R_WL10.1, R_WL13.2, U1.1
unnamed: R_BELT1.2, SAFETY_BELT1.1 (K)
unnamed: R_SRS1.2, SRS1.1 (K)
unnamed: R_TLSC1.2, TLSC_LOCK1.1 (K)
unnamed: R_WL9.1, R_WL10.2, R_WL11.2, U1.3 (+)
unnamed: R_WPR1.2, WIPER_LV1.1 (K)
OIL_SNSR: D33.2 (A), R_OP1.1; also elsewhere on the board
PAD_SNSR: D31.2 (A), R_PAD1.1; also elsewhere on the board
SRS 12V: SRS1.2 (A); also elsewhere on the board
SRS GND: R_SRS1.1; also elsewhere on the board
TLSC_SNSR: D29.2 (A), R_TLSC1.1; also elsewhere on the board
WPR_SNSR: D34.2 (A), R_WPR1.1; also elsewhere on the board

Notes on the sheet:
1K - 12v IGN 470 - 5v
10K R_WL13 is Optional depending on situation
without IGNITION_12v input, a buzzer should ring to warn the user
12V Ignition will trigger GROUND Upon Engine RPM Detected, the GROUND switch will be deactivated

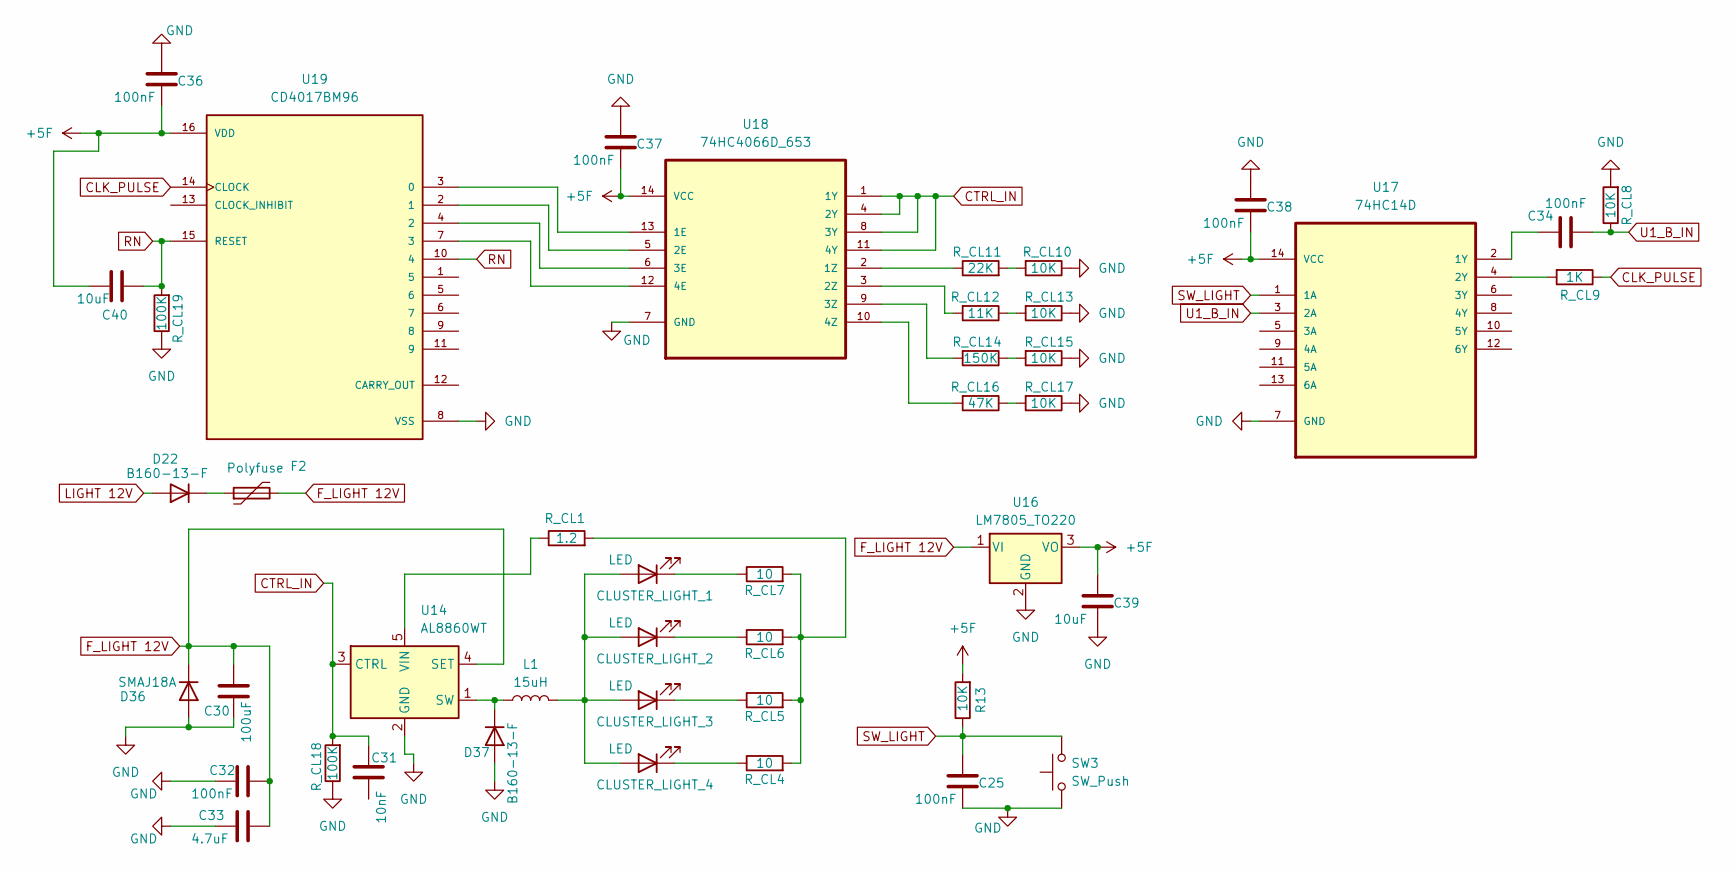
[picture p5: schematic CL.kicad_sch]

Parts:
C25, C32, C34, C36, C37, C38: 100nF; C_0805_2012Metric
C30: 100uF; CP_EIA-7343-31_Kemet-D_HandSolder
C31: 10nF; C_0805_2012Metric
C33: 4.7uF; C_0805_2012Metric
C39, C40: 10uF; C_0805_2012Metric
CLUSTER_LIGHT_1, CLUSTER_LIGHT_2, CLUSTER_LIGHT_3, CLUSTER_LIGHT_4: LED; LED_Everlight-SMD3528_3.5x2.8mm_67-21ST
D22: B160-13-F; D_SMA_Handsoldering
D36: SMAJ18A; D_SMA
D37: B160-13-F; D_SMA
F2: Polyfuse; Fuse_1206_3216Metric_Pad1.42x1.75mm_HandSolder
L1: 15uH; L_Vishay_IFSC-1515AH_4x4x1.8mm
R13: 10K; R_0805_2012Metric
R_CL1: 1.2; R_2512_6332Metric
R_CL4, R_CL5, R_CL6, R_CL7: 10; R_0805_2012Metric
R_CL8, R_CL10, R_CL13, R_CL15, R_CL17: 10K; R_0805_2012Metric
R_CL9: 1K; R_0805_2012Metric
R_CL11: 22K; R_0805_2012Metric
R_CL12: 11K; R_0805_2012Metric
R_CL14: 150K; R_0805_2012Metric
R_CL16: 47K; R_0805_2012Metric
R_CL18, R_CL19: 100K; R_0805_2012Metric
SW3: SW_Push; SW_PUSH_6mm
U14: AL8860WT; TSOT-23-5
U16: LM7805_TO220; TO-220-3_Vertical
U17: 74HC14D; SOIC127P600X175-14N; MPN 74HC14D
U18: 74HC4066D_653; SOIC127P600X175-14N; MPN 74HC4066D,653
U19: CD4017BM96; SOIC127P600X175-16N; PARTREV Feb 2004

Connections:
+5F: C36.2, C37.2, C38.2, C39.1, C40.2, R13.2, U16.3 (VO), U17.14 (VCC), U18.14 (VCC), U19.16 (VDD); also elsewhere on the board
CLK_PULSE: R_CL9.1, U19.14 (CLOCK)
CTRL_IN: C31.1, R_CL18.2, U14.3 (CTRL), U18.1 (1Y), U18.4 (2Y), U18.8 (3Y), U18.11 (4Y)
F_LIGHT 12V: C30.1, C32.1, C33.1, D36.1 (K), F2.2, U14.4 (SET), U16.1 (VI)
GND: C25.2, C30.2, C32.2, C33.2, C36.1, C37.1, C38.1, C39.2, D36.2 (A), D37.2 (A), R_CL8.2, R_CL10.1, R_CL13.1, R_CL15.1, R_CL17.1, R_CL18.1, R_CL19.1, SW3.1, U14.2 (GND), U16.2 (GND), U17.7 (GND), U18.7 (GND), U19.8 (VSS); also elsewhere on the board
LIGHT 12V: D22.2 (A); also elsewhere on the board
unnamed: CLUSTER_LIGHT_1.2 (A), CLUSTER_LIGHT_2.2 (A), CLUSTER_LIGHT_3.2 (A), CLUSTER_LIGHT_4.2 (A), L1.2
unnamed: CLUSTER_LIGHT_1.1 (K), R_CL7.1
unnamed: CLUSTER_LIGHT_2.1 (K), R_CL6.1
unnamed: CLUSTER_LIGHT_3.1 (K), R_CL5.1
unnamed: CLUSTER_LIGHT_4.1 (K), R_CL4.1
unnamed: D22.1 (K), F2.1
unnamed: D37.1 (K), L1.1, U14.1 (SW)
unnamed: R_CL1.2, R_CL4.2, R_CL5.2, R_CL6.2, R_CL7.2
unnamed: R_CL10.2, R_CL11.2
unnamed: R_CL12.1, R_CL13.2
unnamed: R_CL14.1, R_CL15.2
unnamed: R_CL16.1, R_CL17.2
unnamed: R_CL1.1, U14.5 (VIN)
unnamed: C34.1, U17.2 (1Y)
unnamed: R_CL9.2, U17.4 (2Y)
unnamed: U18.13 (1E), U19.3 (0)
unnamed: R_CL11.1, U18.2 (1Z)
unnamed: U18.5 (2E), U19.2 (1)
unnamed: R_CL12.2, U18.3 (2Z)
unnamed: U18.6 (3E), U19.4 (2)
unnamed: R_CL14.2, U18.9 (3Z)
unnamed: U18.12 (4E), U19.7 (3)
unnamed: R_CL16.2, U18.10 (4Z)
RN: C40.1, R_CL19.2, U19.10 (4), U19.15 (RESET)
SW_LIGHT: C25.1, R13.1, SW3.2, U17.1 (1A)
U1_B_IN: C34.2, R_CL8.1, U17.3 (2A)

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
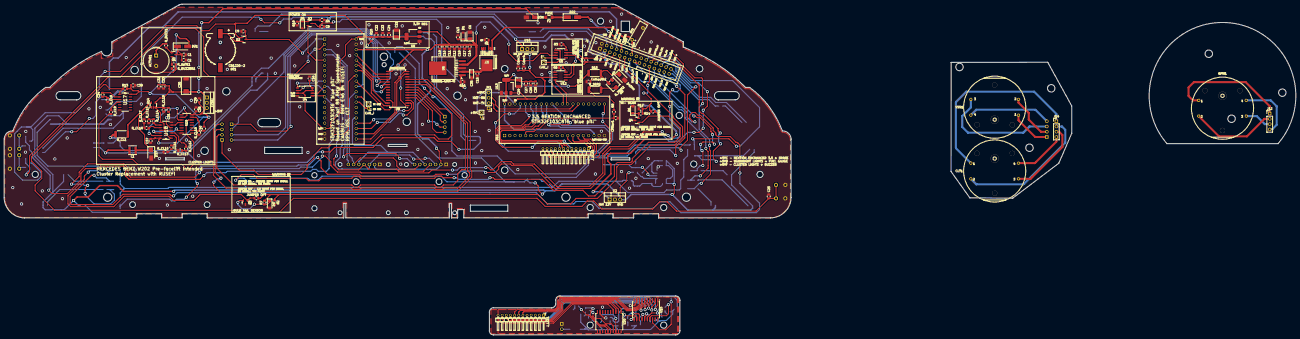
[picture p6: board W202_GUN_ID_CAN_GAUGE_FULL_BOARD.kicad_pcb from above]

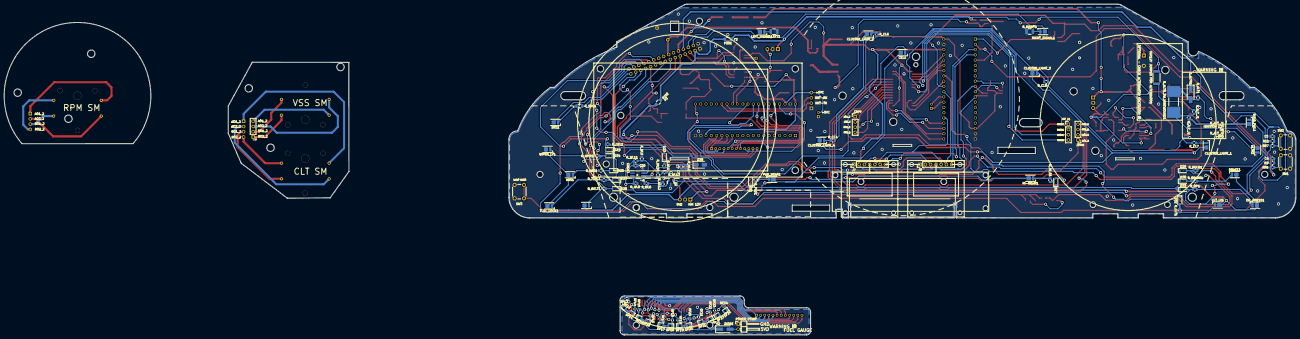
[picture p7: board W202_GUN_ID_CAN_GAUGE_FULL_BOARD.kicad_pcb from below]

Board: 2 copper layers, 380.0 x 103.2 mm, 236 parts (112 on the bottom side), 177 nets.

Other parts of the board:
+5VC: PinHeader_1x02_P2.00mm_Vertical
CAN_J: PinHeader_1x02_P2.00mm_Vertical
CAN_J#2: PinHeader_1x02_P2.00mm_Vertical
DIODE: 1N4007; D_SMA_Handsoldering
F3, F3#2: Polyfuse; Fuse_1206_3216Metric_Pad1.42x1.75mm_HandSolder
IGN12V JUMPER FOR ALTERNATOR: 10; R_2512_6332Metric
J3#2: VSS; PinHeader_1x04_P2.54mm_Vertical
JUMPER OPT: R_0805_2012Metric
JUMPER OPT#2: R_0805_2012Metric
POWER POINT: PinHeader_1x02_P2.54mm_Horizontal
R_WL8: 47K; R_0805_2012Metric

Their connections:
+5C: +5VC.2; also elsewhere on the board
+5VD: DIODE.1 (K), R_WL8.1; also elsewhere on the board
+5VD_S: DIODE.2 (A), POWER POINT.2
AO1_1: J3#2.1; also elsewhere on the board
AO2_1: J3#2.2; also elsewhere on the board
BO1_1: J3#2.3; also elsewhere on the board
BO2_1: J3#2.4; also elsewhere on the board
BULB_SNSR: JUMPER OPT.2; also elsewhere on the board
GND: +5VC.1, POWER POINT.1; also elsewhere on the board
HI_BEAM: JUMPER OPT#2.1; also elsewhere on the board
unnamed 69: JUMPER OPT.1; also elsewhere on the board
unnamed 70: JUMPER OPT#2.2; also elsewhere on the board
unnamed 104: R_WL8.2; also elsewhere on the board
RX CAN: CAN_J.1, CAN_J#2.1; also elsewhere on the board
TX CAN: CAN_J.2, CAN_J#2.2; also elsewhere on the board

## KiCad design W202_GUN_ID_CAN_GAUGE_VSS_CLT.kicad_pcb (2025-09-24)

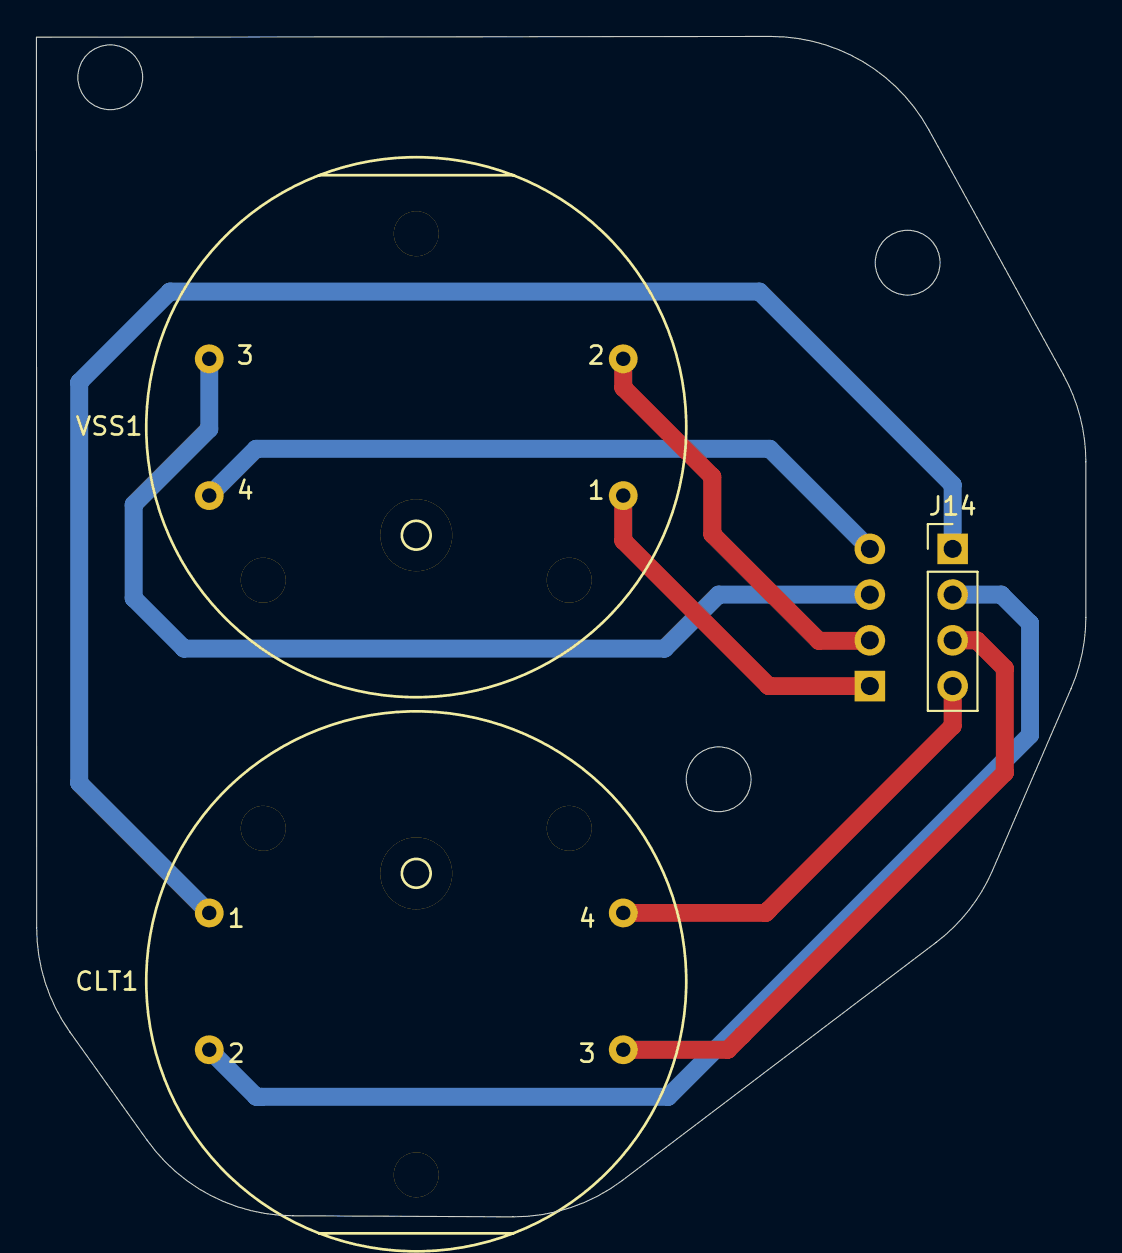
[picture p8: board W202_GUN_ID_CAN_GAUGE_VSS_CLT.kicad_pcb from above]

Board: 2 copper layers, 58.3 x 65.6 mm, 4 parts (1 on the bottom side), 8 nets.

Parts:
CLT1: SM; X27-168__V2
J3: VSS; PinHeader_1x04_P2.54mm_Vertical
J14: CLT; PinHeader_1x04_P2.54mm_Vertical
VSS1: SM; X27-168__V2

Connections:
AO1_1: J3.1, VSS1.1
AO2_1: J3.2, VSS1.2 (-)
BO1_1: J3.3, VSS1.3
BO2_1: J3.4, VSS1.4
OUT_1C: CLT1.1, J14.1
OUT_2C: CLT1.2 (-), J14.2
OUT_3C: CLT1.4, J14.4
OUT_4C: CLT1.3, J14.3
